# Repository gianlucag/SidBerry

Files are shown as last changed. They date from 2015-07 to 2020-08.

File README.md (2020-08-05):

## SidBerry ##
### Music player per chip SID 6581 realizzato con RaspberryPi ###

Un SID jukebox realizzato con RasberryPi e il SID chip originale 6581. Il chip è alloggiato in una board custom collegata direttamente ai GPIO del Rasberry!

(http://youtu.be/i_vNFhmKoK4)

La board può riprodurre qualsiasi SID file, basta caricare i file .sid nella sdcard del Rasberry, avviare il player e collegare all'uscita jack un paio di casse preamplificate o meglio uno stereo.

### SID chip ###

Il SID originale, nelle varianti 6581 e 8580, è controllato caricando i suoi 29 registri interni con i valori opportuni al momento opportuno. La sequenza di byte inviati genera l'effetto o la musica desiderati. Ogni registro è 1 byte ed i registri sono in tutto 29 quindi c'è bisogno di almeno 5 gpio di indirizzo (2^5=32) e 8 gpio di dati per un totale di 13 gpio. Un altro gpio è richiesto per la linea CS del chip (Chip Select).

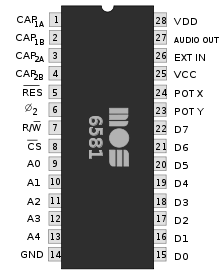
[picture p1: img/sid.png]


Fortunatamente il Raspberry ha ben 17 gpio e i 14 richiesti sono perfettamente pilotabili con la libreria WiringPi. Gli altri pin del chip servono per i due condensatori dei filtri interni (CAP_a e CAP_b), alimentazione, linea R/W (che andremo a collegare direttamente a GND, siamo sempre in scrittura), entrata del segnale di clock, linea di reset (collegata sempre a VCC) e uscita audio analogica (AUDIO OUT).

Ecco la configurazione dei registri interni del SID:

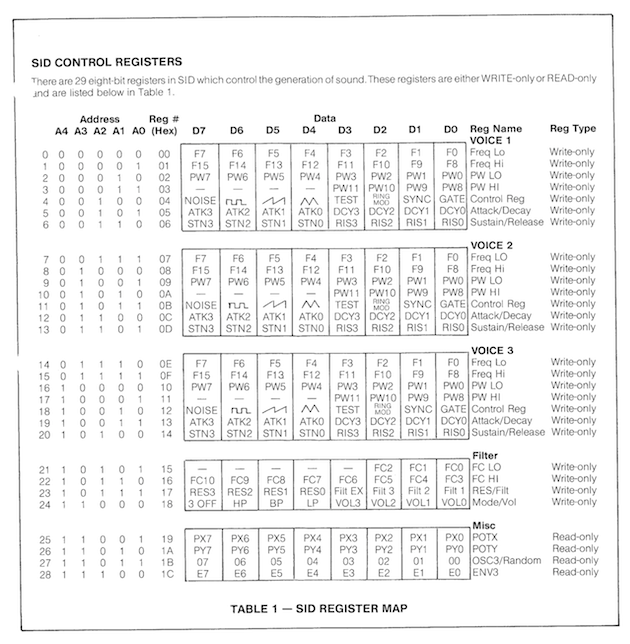
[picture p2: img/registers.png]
registers


Qui per una descrizione più dettagliata del funzionamento interno del chip:

http://www.waitingforfriday.com/index.php/Commodore_SID_6581_Datasheet

### Hardware ###

La board riproduce esattamente le "condizioni al contorno" per il SID chip come se si trovasse alloggiato in un Commodore 64 originale. L'application note originale mostra chiaramente i collegamenti da effettuare e i pochi componenti esterni richiesti (generatore di clock, condensatori e poco altro).

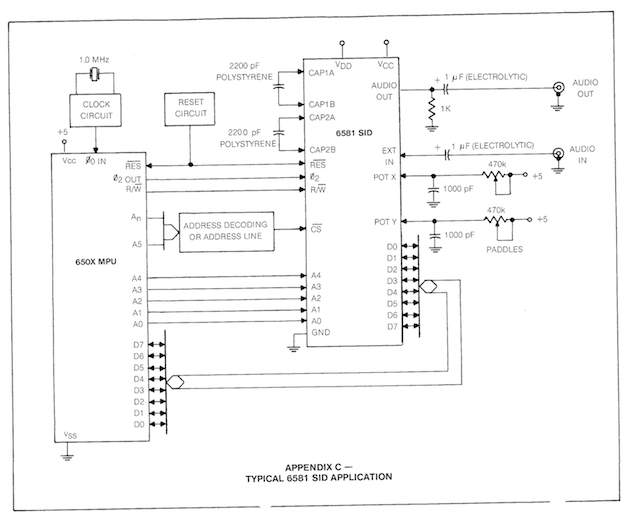
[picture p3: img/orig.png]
orig


Unica differenza, le linee di indirizzo e dati vengono dirottate direttamente sui gpio del RasberryPi.

NOTA IMPORTANTE!: Il RasberryPi ragiona in logica CMOS a 3.3V mentre il SID chip è TTL a 5V quindi completamente incompatibili a livello di tensioni. Fortunatamente, siccome andiamo unicamente a scrivere nei registri, il RasberryPi dovrà soltanto applicare 3.3v ai capi del chip, più che sufficienti per essere interpretati come livello logico alto dal SID.

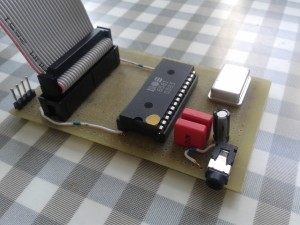
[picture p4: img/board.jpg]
board


Lo schematico completo:

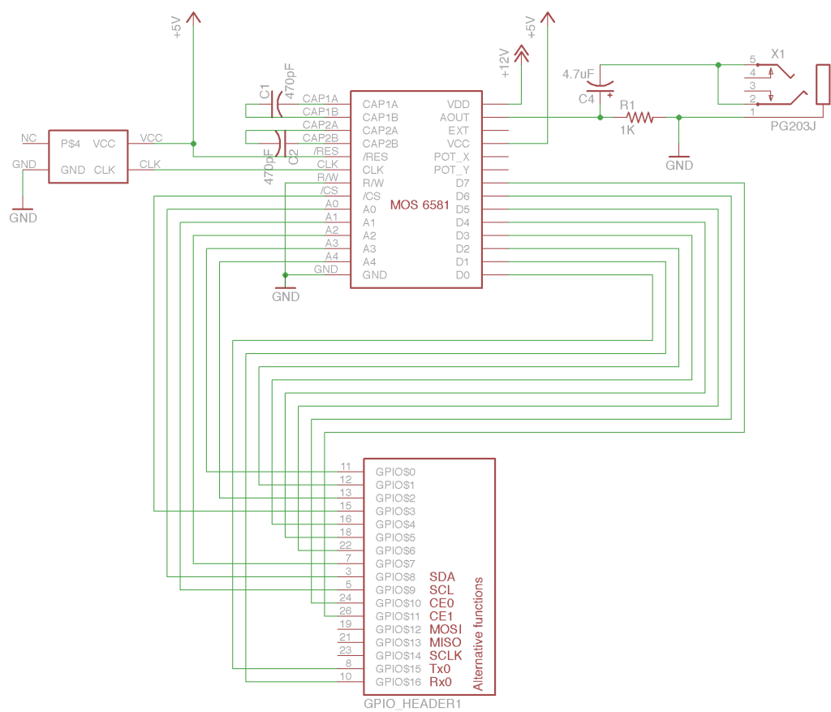
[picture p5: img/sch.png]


### Software ###

Il grosso del lavoro. Volevo una soluzione completamente stand-alone, senza l'ausilio di player esterni (come ACID64) e quindi ho realizzato un player che emula gran parte di un C64 originale. L'emulatore è necessario in quanto i file .sid sono programmi in linguaggio macchina 6502 e come tali devono essere eseguiti. Il player è scritto in C/C++ e basato sul mio emulatore MOS CPU 6502   più un semplice array di 65535 byte come memoria RAM (il C64 originale ha infatti 64K di RAM). Il player carica il codice programma contenuto nel file .sid nella RAM virtuale più un codice assembly aggiuntivo che ho chiamato micro-player: sostanzialmente si tratta di un programma minimale scritta in linguaggio macchina per CPU 6502 che assolve a due compiti specifici:

 * installare i vettori di reset e interrupt alle locazioni corrette
 * chiamare la play routine del codice sid ad ogni interrupt

Questo perchè il codice che genera la musica in un comune C64 è una funzione chiamata ad intervalli regolari (50 volte al secondo, 50Hz). La chiamata è effettuata per mezzo di un interrupt esterno. In questo modo è possibile avere musica e un qualsiasi altro programma (videogioco ad esempio) in esecuzione nello stesso momento.

Altre componenti sono il parser per i file .sid e la libreria WiringPi per pilotare i GPIO del RaspberryPi.

Questo il layout dell'intero applicativo, a destra è la memoria RAM virtuale 64K

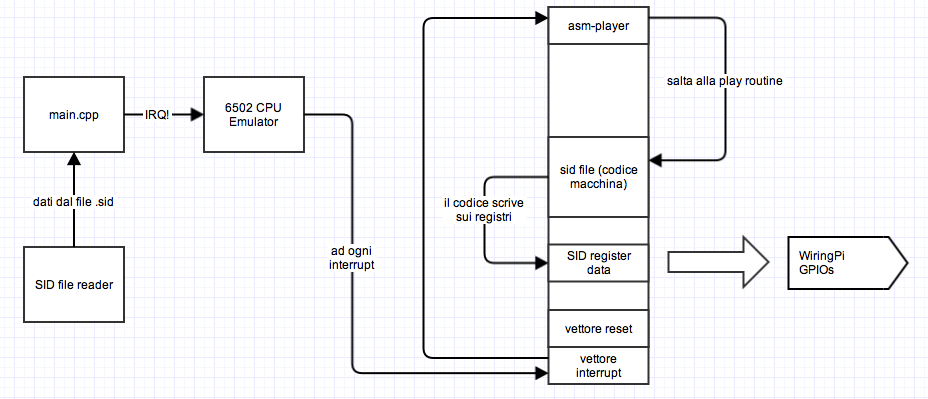
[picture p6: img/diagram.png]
layout


Questo è il codice assembler del micro-player:

```
// istallazione del vettore di reset (0x0000)
memory[0xFFFD] = 0x00;
memory[0xFFFC] = 0x00;</p>
// istallazione del vettore di interrupt, punta alla play routine (0x0013)
memory[0xFFFF] = 0x00;
memory[0xFFFE] = 0x13;

// codice del micro-player
memory[0x0000] = 0xA9;
memory[0x0001] = atoi(argv[2]); // il registro A viene caricato con il numero della traccia (0-16)

memory[0x0002] = 0x20; // salta alla init-routine nel codice sid
memory[0x0003] = init &amp; 0xFF; // lo addr
memory[0x0004] = (init &gt;&gt; 8) &amp; 0xFF; // hi addr

memory[0x0005] = 0x58; // abilitiamo gli interrupt
memory[0x0006] = 0xEA; // nop
memory[0x0007] = 0x4C; // loop infinito
memory[0x0008] = 0x06;
memory[0x0009] = 0x00;

// Interrupt service routine (ISR)
memory[0x0013] = 0xEA; // nop
memory[0x0014] = 0xEA; // nop
memory[0x0015] = 0xEA; // nop
memory[0x0016] = 0x20; // saltiamo alla play routine
memory[0x0017] = play &amp; 0xFF;
memory[0x0018] = (play &gt;&gt; 8) &amp; 0xFF;
memory[0x0019] = 0xEA; // nop
memory[0x001A] = 0x40; // return from interrupt
```
### Modifiche al Software introdotte da Alessio Lombardo ###
- Bug-Fixing (si ringrazia Thoroide, https://www.gianlucaghettini.net/sidberry2-raspberry-pi-6581-sid-player/)
- Possibilità di compilare il sorgente per diverse schede/SoC. Oltre a RaspberryPI, è direttamente supportata la scheda Acme Systems AriettaG25. Altre schede possono essere aggiunte editando opportunamente i file "gpioInterface.cpp" e "gpioInterface.h". Se necessario, è possibile fare riferimento a librerie esterne per la gestione delle porte GPIO (ad esempio, "wiringPi" nel caso di Rapsberry o "wiringSam" nel caso di Arietta).
- Aggiunti controlli al player: Pausa/Continua, traccia precedente/successiva, Restart, Uscita (con reset dei registri), Modalità Verbose.

Per la scheda AriettaG25 con libreria "wiringSAM" già installata compilare con:
```
g++ *.cpp -D BOARD='ARIETTAG25' -o sidberry -lwiringSam
```
Per la scheda RaspberryPI con libreria "wiringPi" già installata compilare con:
```
g++ *.cpp -D BOARD='RASPBERRYPI' -o sidberry -lwiringPi
```
Per altre schede, dopo aver opportunamente modificato "gpioInterface.cpp" e "gpioInterface.h", compilare con:
```
g++ *.cpp -D BOARD='CUSTOM' -o sidberry
```

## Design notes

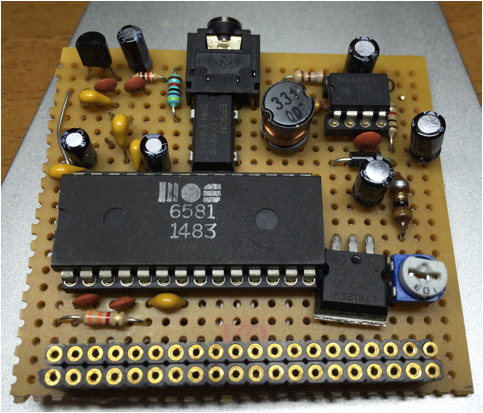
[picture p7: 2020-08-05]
hardware/Raspberry Pi/SidBerry_RaspberryPi_by_Thoroide_board2.png

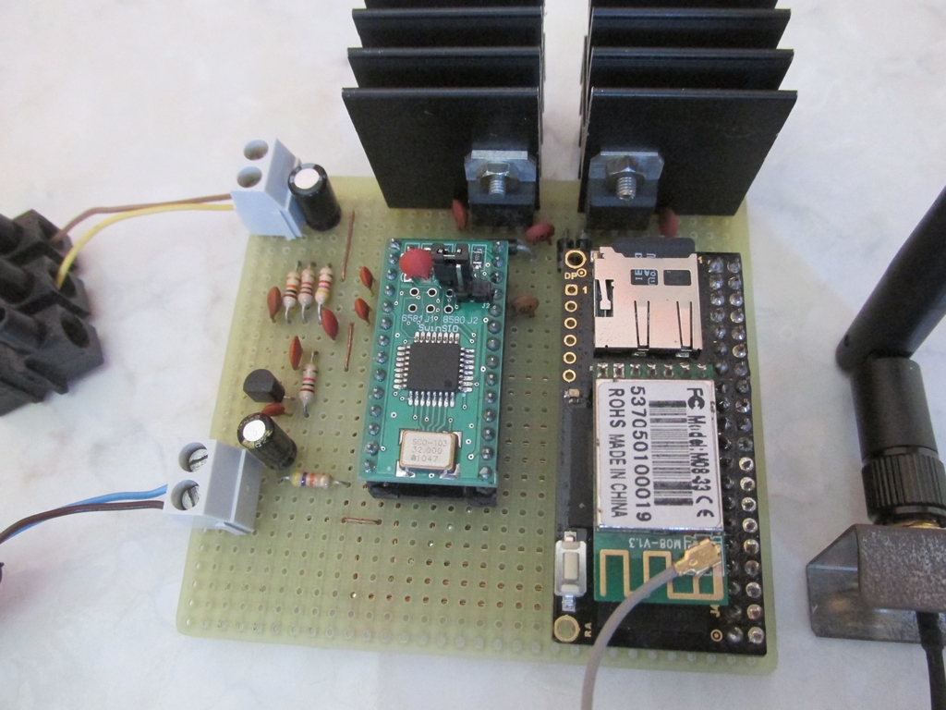
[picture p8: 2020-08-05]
hardware/Arietta G25/SidBerry_AriettaG25_board2.JPG

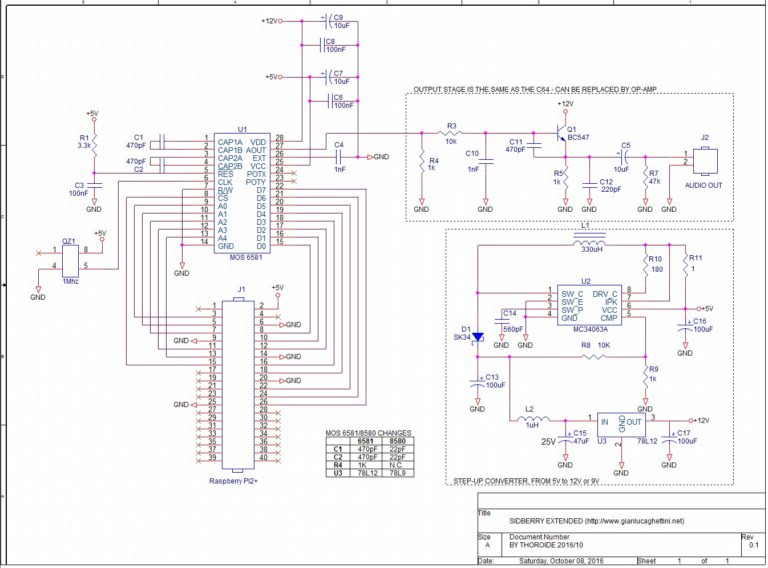
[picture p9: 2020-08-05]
hardware/Raspberry Pi/SidBerry_RaspberryPi_by_Thoroide_schematic.jpg

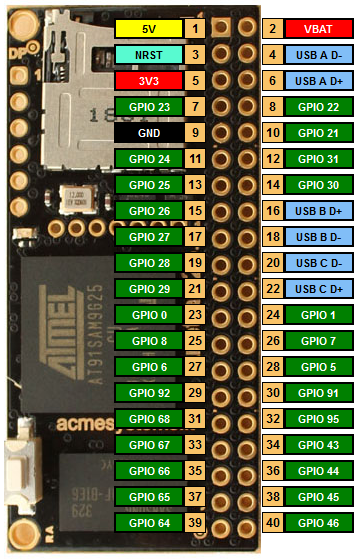
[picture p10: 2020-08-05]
hardware/Arietta G25/AriettaG25_pinout.png

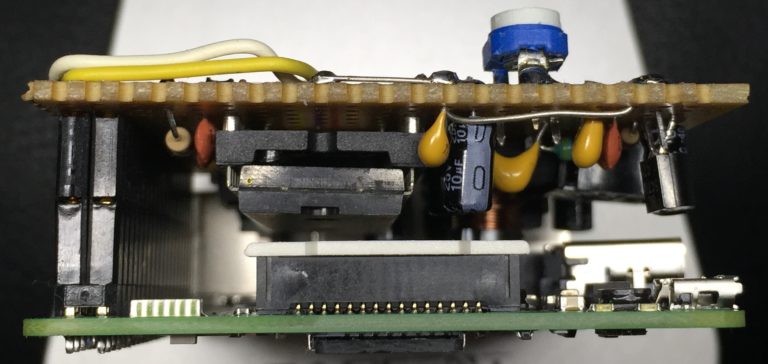
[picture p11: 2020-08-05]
hardware/Raspberry Pi/SidBerry_RaspberryPi_by_Thoroide_board3.jpg

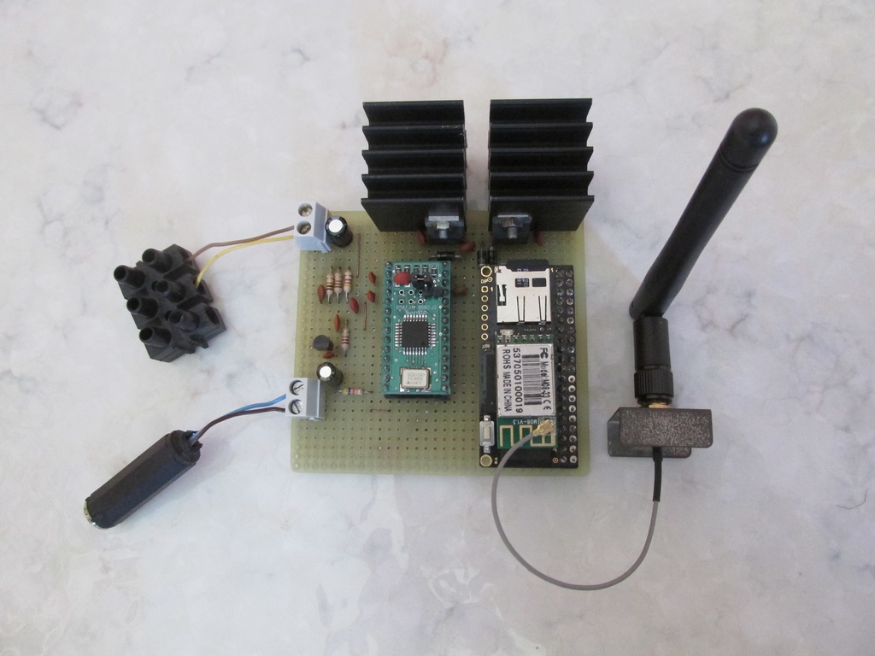
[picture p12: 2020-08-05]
hardware/Arietta G25/SidBerry_AriettaG25_board1.JPG

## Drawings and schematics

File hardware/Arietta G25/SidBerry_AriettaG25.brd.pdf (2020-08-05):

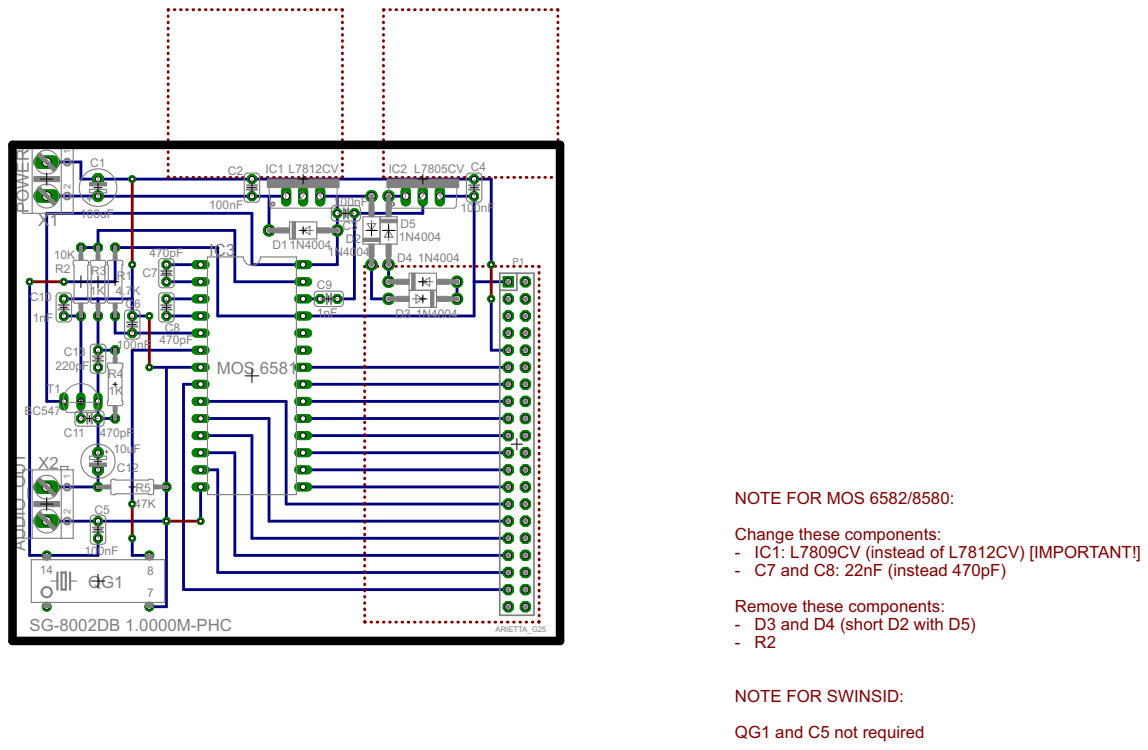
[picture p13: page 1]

NOTE FOR MOS 6582/8580: Change these components: - IC1: L7809CV (instead of L7812CV) [IMPORTANT!] - C7 and C8: 22nF (instead 470pF)

Remove these components: - D3 and D4 (short D2 with D5)

NOTE FOR SWINSID: QG1 and C5 not required

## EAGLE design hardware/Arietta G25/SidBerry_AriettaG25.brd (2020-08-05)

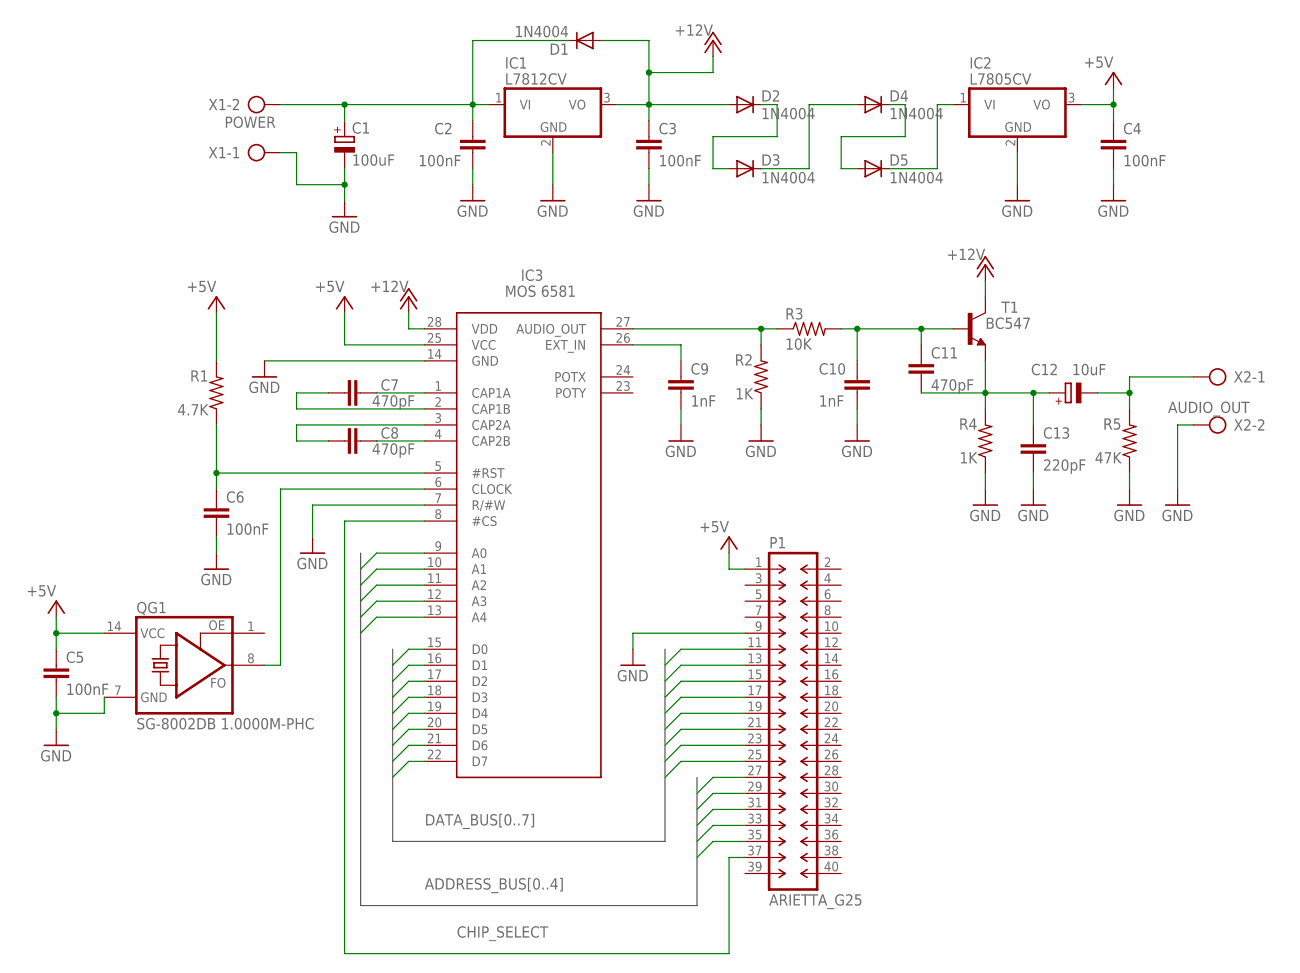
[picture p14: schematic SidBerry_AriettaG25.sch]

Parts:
C1: 100uF; E2,5-6
C2, C3, C4, C5, C6: 100nF; C025-024X044
C7, C8, C11: 470pF; C025-024X044
C9, C10: 1nF; C025-024X044
C12: 10uF; E2,5-5
C13: 220pF; C025-024X044
D1, D2, D3, D4, D5: 1N4004; DO41-10
IC1: L7812CV; TO220V
IC2: L7805CV; TO220V
IC3: MOS 6581; DIL28-6
P1: ARIETTA_G25; DIL-100-2X20
QG1: SG-8002DB 1.0000M-PHC; SG51
R1: 4.7K; 0207/10
R2, R4: 1K; 0207/10
R3: 10K; 0207/10
R5: 47K; 0207/10
T1: BC547; TO92-CBE
X1: POWER; AK500/2
X2: AUDIO_OUT; AK500/2

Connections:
+5V: C4.1, C5.1, IC2.3 (VO), IC3.25 (VCC), P1.1, QG1.14 (VCC), R1.2
+12V: C3.1, D1.A, D2.A, IC1.3 (VO), IC3.28 (VDD), T1.C
ADDRESS_BUS0: IC3.9 (A0), P1.27
ADDRESS_BUS1: IC3.10 (A1), P1.29
ADDRESS_BUS2: IC3.11 (A2), P1.31
ADDRESS_BUS3: IC3.12 (A3), P1.33
ADDRESS_BUS4: IC3.13 (A4), P1.35
CHIP_SELECT: IC3.8 (#CS), P1.37
DATA_BUS0: IC3.15 (D0), P1.25
DATA_BUS1: IC3.16 (D1), P1.23
DATA_BUS2: IC3.17 (D2), P1.21
DATA_BUS3: IC3.18 (D3), P1.19
DATA_BUS4: IC3.19 (D4), P1.17
DATA_BUS5: IC3.20 (D5), P1.15
DATA_BUS6: IC3.21 (D6), P1.13
DATA_BUS7: IC3.22 (D7), P1.11
GND: C1.-, C2.2, C3.2, C4.2, C5.2, C6.2, C9.2, C10.2, C13.2, IC1.2 (GND), IC2.2 (GND), IC3.7 (R/#W), IC3.14 (GND), P1.9, QG1.7 (GND), R2.1, R4.1, R5.1, X1.1, X2.2
unnamed: IC3.6 (CLOCK), QG1.8 (FO)
unnamed: C9.1, IC3.26 (EXT_IN)
unnamed: D2.C, D3.A
unnamed: D3.C, D4.A
unnamed: D4.C, D5.A
unnamed: D5.C, IC2.1 (VI)
unnamed: C8.2, IC3.4 (CAP2B)
unnamed: C8.1, IC3.3 (CAP2A)
unnamed: C7.1, IC3.2 (CAP1B)
unnamed: C7.2, IC3.1 (CAP1A)
unnamed: C6.1, IC3.5 (#RST), R1.1
unnamed: IC3.27 (AUDIO_OUT), R2.2, R3.1
unnamed: C1.+, C2.1, D1.C, IC1.1 (VI), X1.2
unnamed: C12.-, R5.2, X2.1
unnamed: C10.1, C11.1, R3.2, T1.B
unnamed: C11.2, C12.+, C13.1, R4.2, T1.E

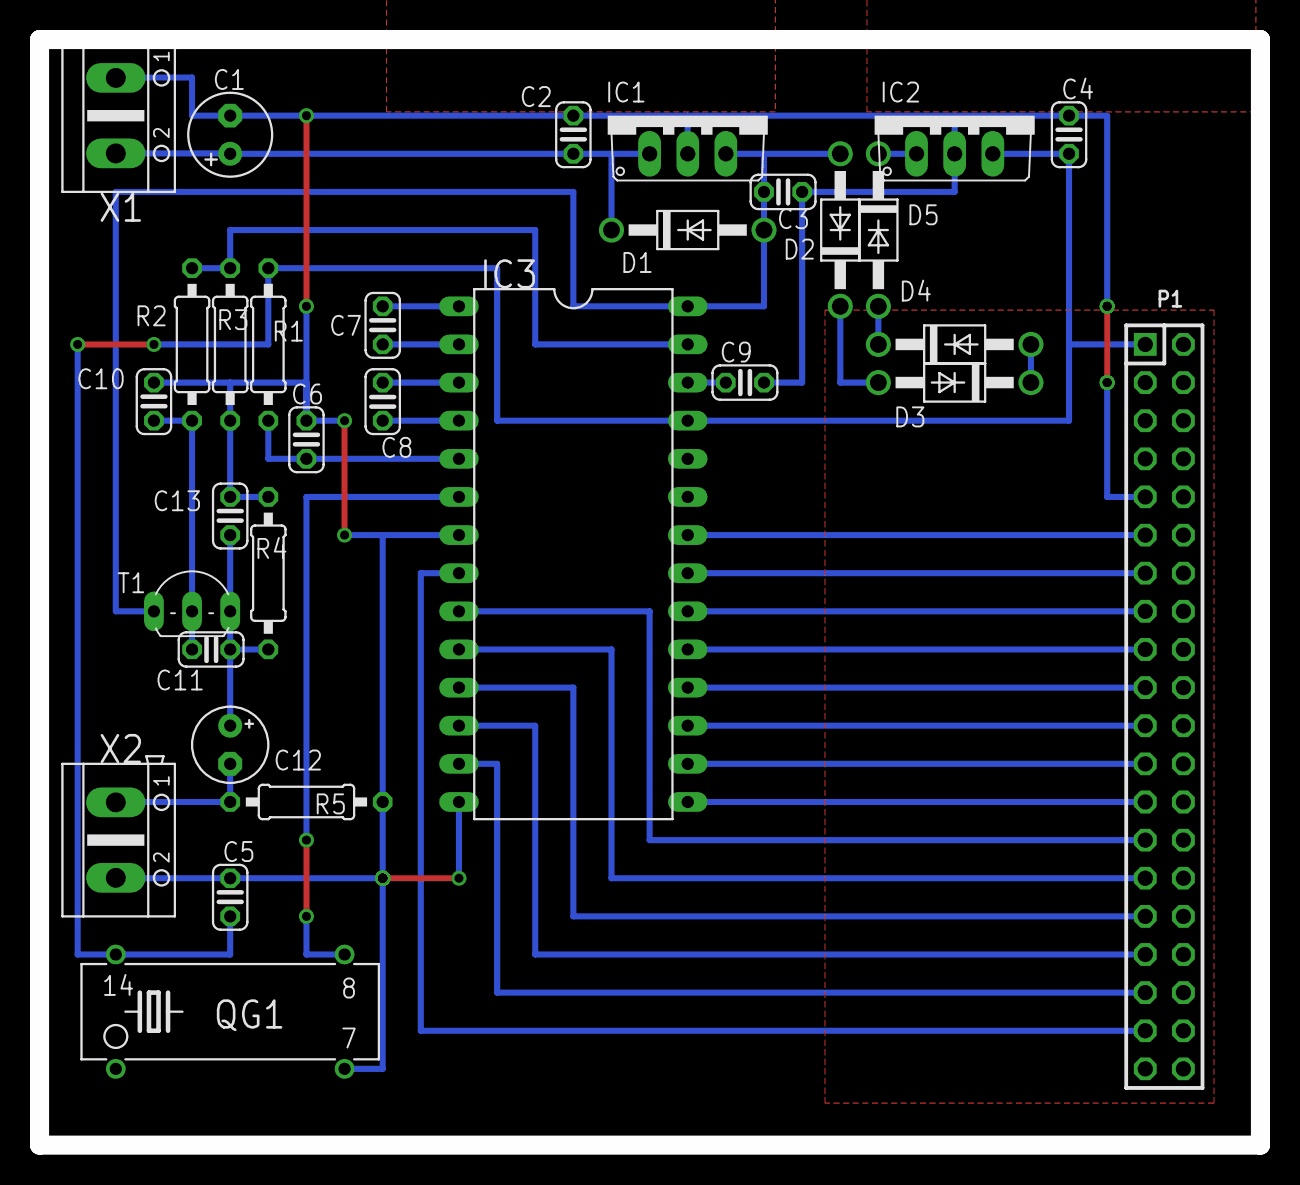
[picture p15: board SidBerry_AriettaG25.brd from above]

Board: 2 copper layers, 81.3 x 73.6 mm, 32 parts (0 on the bottom side), 33 nets.

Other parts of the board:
U$1: A4L-LOC

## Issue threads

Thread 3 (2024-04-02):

Issues on RPi4

LouDnl, 2024-04-02:
I am having issues trying to get this to run on my Pi4. I can compile it without any problems, but running it has had me banging my head. Have you seen this before?

# run with debug
```bash
└─$ sudo WIRINGPI_DEBUG=1 ./sidberry R-Type.sid

< Sid Info >
Module Name       : R-Type
Author Name       : Chris H�lsbeck & Ramiro Vaca
Copyright         :
Load Address      : 12692
Init Address      : 12692
Play Address      : 25456
Selected Sub-Song : 1 / 14
wiringPi: wiringPiSetup called
GetPiRevision: Revision string: "Revision       : c03115" (c03115) - 0xc03115
piBoardId: New Way: revision is: 00C03115
piBoardId: rev: 5, type: 17, proc: 3, mfg: 0, mem: 4, warranty: 0
wiringPi: access to /dev/mem succeded
wiringPi: memory map gpio  0xfe200000 valid
wiringPi: memory map pads  0xfe100000 valid
wiringPi: memory map rio   0x0 invalid
wiringPi: memory map pwm   0xfe20c000 valid
wiringPi: memory map clk   0xfe101000 valid
wiringPi: memory map timer 0xfe00b000 valid
pinMode: pin:27 mode:1
pinMode: bcm pin:16 mode:1
pinMode: pin:28 mode:1
pinMode: bcm pin:20 mode:1
pinMode: pin:29 mode:1
pinMode: bcm pin:21 mode:1
pinMode: pin:4 mode:1
pinMode: bcm pin:23 mode:1
pinMode: pin:5 mode:1
pinMode: bcm pin:24 mode:1
pinMode: pin:6 mode:1
pinMode: bcm pin:25 mode:1
pinMode: pin:10 mode:1
pinMode: bcm pin:8 mode:1
pinMode: pin:11 mode:1
pinMode: bcm pin:7 mode:1
pinMode: pin:8 mode:1
pinMode: bcm pin:2 mode:1
pinMode: pin:9 mode:1
pinMode: bcm pin:3 mode:1
pinMode: pin:7 mode:1
pinMode: bcm pin:4 mode:1
pinMode: pin:0 mode:1
pinMode: bcm pin:17 mode:1
pinMode: pin:2 mode:1
pinMode: bcm pin:27 mode:1
pinMode: pin:3 mode:1
pinMode: bcm pin:22 mode:1
zsh: illegal hardware instruction  sudo WIRINGPI_DEBUG=1 ./sidberry R-Type.sid
```

# gdb
```bash
└─$ sudo gdb --args sidberry R-Type.sid
GNU gdb (Debian 13.2-1) 13.2
Copyright (C) 2023 Free Software Foundation, Inc.
License GPLv3+: GNU GPL version 3 or later <http://gnu.org/licenses/gpl.html>
This is free software: you are free to change and redistribute it.
There is NO WARRANTY, to the extent permitted by law.
Type "show copying" and "show warranty" for details.
This GDB was configured as "arm-linux-gnueabihf".
Type "show configuration" for configuration details.
For bug reporting instructions, please see:
<https://www.gnu.org/software/gdb/bugs/>.
Find the GDB manual and other documentation resources online at:
    <http://www.gnu.org/software/gdb/documentation/>.

For help, type "help".
Type "apropos word" to search for commands related to "word"...
Reading symbols from sidberry...
(gdb) r
Starting program: /home/loud/development/SidBerry/sidberry R-Type.sid
[Thread debugging using libthread_db enabled]
Using host libthread_db library "/lib/arm-linux-gnueabihf/libthread_db.so.1".

< Sid Info >
Module Name       : R-Type
Author Name       : Chris H�lsbeck & Ramiro Vaca
Copyright         :
Load Address      : 12692
Init Address      : 12692
Play Address      : 25456
Selected Sub-Song : 1 / 14

Program received signal SIGILL, Illegal instruction.
0x00401da4 in load_sid (cpu=..., sid=<error reading variable: value of type `SidFile' requires 65640 bytes, which is more than max-value-size>, song_number=0) at main.cpp:278
278             cpu.Run(10000000);
```

LouDnl, 2024-04-03:
Got it working, the issue was with `load_sid` being int without a return. Changing it to `void load_sid` fixed all issues.

gianlucag, 2024-04-04:
Good catch. Please feel free to submit a pull request if you want.

LouDnl, 2024-04-08:
Since i've got it working I can notice that the timing sometimes seems off and tunes don't always play all notes. Have you seen/ heard this before?

LouDnl, 2024-05-12:
@gianlucag decided to create a fork because I made so many changes it wouldnt be fair for me to decide what you want and dont want 🙂

https://github.com/LouDnl/SidBerry

Closed 2024-05-07.

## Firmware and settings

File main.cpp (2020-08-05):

//============================================================================
// Description : SidBerry player & driver 
// Author      : Gianluca Ghettini, Alessio Lombardo
//============================================================================

#include <iostream>
using namespace std;
#include <stdlib.h>
#include "mos6502.h"
#include "SidFile.h"
#include <sys/time.h>
#include <unistd.h>
#include <fcntl.h>
#include <termios.h>

#include "gpioInterface.h"

uint8_t memory[65536]; // 64K ram
bool verbose = false;

void TestWrite(uint16_t addr, uint8_t byte)
{	
		printf("\na: %02X, b: %02X", addr, byte);		
		
		uint16_t phyaddr = addr;
		
		// set address to the bus
		if(phyaddr & 0x01) gpioWrite(A0, HIGH);
		else gpioWrite(A0, LOW);
		if(phyaddr & 0x02) gpioWrite(A1, HIGH);
		else gpioWrite(A1, LOW);
		if(phyaddr & 0x04) gpioWrite(A2, HIGH);
		else gpioWrite(A2, LOW);
		if(phyaddr & 0x08) gpioWrite(A3, HIGH);
		else gpioWrite(A3, LOW);
		if(phyaddr & 0x10) gpioWrite(A4, HIGH);
		else gpioWrite(A4, LOW);
		
		// set data to the bus
		if(byte & 0x01) gpioWrite(D0, HIGH);
		else gpioWrite(D0, LOW);
		if(byte & 0x02) gpioWrite(D1, HIGH);
		else gpioWrite(D1, LOW);
		if(byte & 0x04) gpioWrite(D2, HIGH);
		else gpioWrite(D2, LOW);
		if(byte & 0x08) gpioWrite(D3, HIGH);
		else gpioWrite(D3, LOW);
		if(byte & 0x10) gpioWrite(D4, HIGH);
		else gpioWrite(D4, LOW);			
		if(byte & 0x20) gpioWrite(D5, HIGH);
		else gpioWrite(D5, LOW);
		if(byte & 0x40) gpioWrite(D6, HIGH);
		else gpioWrite(D6, LOW);
		if(byte & 0x80) gpioWrite(D7, HIGH);
		else gpioWrite(D7, LOW);		
		
		// assert cs line
		gpioWrite(CS, LOW);
		usleep(500000);		
		gpioWrite(CS, HIGH);	

	printf("\nOK\n");

	return;
}

void MemWrite(uint16_t addr, uint8_t byte)
{	
	if(addr >= 0xD400 && addr <= 0xD7FF) // address decoding login
	{
		// access to SID chip
		
		memory[addr] = byte;

		if(verbose){
			//NOTE: If you use a slow connection to tty device, the printf function may affect the playback speed
			printf("%02X%02X %02X%02X %02X %02X %02X %02X%02X %02X%02X %02X %02X %02X %02X%02X %02X%02X %02X %02X %02X\n",
					memory[0xD400], memory[0xD401], memory[0xD402], memory[0xD403],memory[0xD404], memory[0xD405], memory[0xD406],
					memory[0xD407], memory[0xD408], memory[0xD409], memory[0xD40A],memory[0xD40B], memory[0xD40C], memory[0xD40D],
					memory[0xD40E], memory[0xD40F], memory[0xD410], memory[0xD411],memory[0xD412], memory[0xD413], memory[0xD414]
			);
		}
		
		uint16_t phyaddr = addr & 0x1f;
		
		// set address to the bus
		if(phyaddr & 0x01) gpioWrite(A0, HIGH);
		else gpioWrite(A0, LOW);
		if(phyaddr & 0x02) gpioWrite(A1, HIGH);
		else gpioWrite(A1, LOW);
		if(phyaddr & 0x04) gpioWrite(A2, HIGH);
		else gpioWrite(A2, LOW);
		if(phyaddr & 0x08) gpioWrite(A3, HIGH);
		else gpioWrite(A3, LOW);
		if(phyaddr & 0x10) gpioWrite(A4, HIGH);
		else gpioWrite(A4, LOW);
		
		// set data to the bus
		if(byte & 0x01) gpioWrite(D0, HIGH);
		else gpioWrite(D0, LOW);
		if(byte & 0x02) gpioWrite(D1, HIGH);
		else gpioWrite(D1, LOW);
		if(byte & 0x04) gpioWrite(D2, HIGH);
		else gpioWrite(D2, LOW);
		if(byte & 0x08) gpioWrite(D3, HIGH);
		else gpioWrite(D3, LOW);
		if(byte & 0x10) gpioWrite(D4, HIGH);
		else gpioWrite(D4, LOW);			
		if(byte & 0x20) gpioWrite(D5, HIGH);
		else gpioWrite(D5, LOW);
		if(byte & 0x40) gpioWrite(D6, HIGH);
		else gpioWrite(D6, LOW);
		if(byte & 0x80) gpioWrite(D7, HIGH);
		else gpioWrite(D7, LOW);		
		
		// assert CS line (strobe)
		gpioWrite(CS, LOW);
		usleep(1);		
		gpioWrite(CS, HIGH);	
	}
	else
	{
		// access to memory
		memory[addr] = byte;
	}
	return;
}

uint8_t MemRead(uint16_t addr)
{
	if(addr >= 0xD400 && addr <=0xD7FF) // address decoding logic
	{
		// access to SID chip
		if((addr & 0x00FF) == 0x001B)
		{
			// emulate read access to OSC3/Random register, return a random value
			printf("\nread! 1b");
			return rand();
		}
		if((addr & 0x00FF) == 0x001C)
		{
			// emulate access to envelope ENV3 register, return a random value
			printf("\nread! 1c");
			return rand();
		}
    }
	return memory[addr];
}

void TestLoop()
{
	int addr;
	int byte;
	printf("\n\n");

	while(1)
	{
		printf("\naddr:");
		scanf("%d", &addr);
		printf("\nbyte:");
		scanf("%d", &byte);
		TestWrite(addr, byte); 
	}	

}

int load_sid(mos6502 cpu, SidFile sid, int song_number){
	for(unsigned int i = 0; i < 65536; i++)
	{
		memory[i] = 0x00; // fill with NOPs
	}
	
	uint16_t load = sid.GetLoadAddress();
	uint16_t len = sid.GetDataLength();
	uint8_t *buffer = sid.GetDataPtr();
	for(unsigned int i = 0; i <  len; i++)
	{
		memory[i + load] = buffer[i];
	}
	
	uint16_t play = sid.GetPlayAddress();
	uint16_t init = sid.GetInitAddress();
	
	
	// install reset vector for microplayer (0x0000)
	memory[0xFFFD] = 0x00;
	memory[0xFFFC] = 0x00;
	
	// install IRQ vector for play routine launcher (0x0013)
	memory[0xFFFF] = 0x00;
	memory[0xFFFE] = 0x13;
	

	// install the micro player, 6502 assembly code
	 
	memory[0x0000] = 0xA9; // A = 0, load A with the song number
	memory[0x0001] = song_number;
	
	memory[0x0002] = 0x20; // jump sub to INIT routine
	memory[0x0003] = init & 0xFF; // lo addr
	memory[0x0004] = (init >> 8) & 0xFF; // hi addr
	
	memory[0x0005] = 0x58; // enable interrupt
	memory[0x0006] = 0xEA; // nop
	memory[0x0007] = 0x4C; // jump to 0x0006
	memory[0x0008] = 0x06;
	memory[0x0009] = 0x00;
	
	memory[0x0013] = 0xEA; // nop  //0xA9; // A = 1
	memory[0x0014] = 0xEA; // nop //0x01;	
	memory[0x0015] = 0xEA; // 0x78 CLI
	memory[0x0016] = 0x20; // jump sub to play routine
	memory[0x0017] = play & 0xFF;
	memory[0x0018] = (play >> 8) & 0xFF;
	memory[0x0019] = 0xEA; // 0x58 SEI	
	memory[0x001A] = 0x40; // RTI: return from interrupt
	
	// setup wiring library, configure GPIOs
	gpioSetup();
	
	gpioMode(D0, OUTPUT);
	gpioMode(D1, OUTPUT);
	gpioMode(D2, OUTPUT);
	gpioMode(D3, OUTPUT);
	gpioMode(D4, OUTPUT);
	gpioMode(D5, OUTPUT);
	gpioMode(D6, OUTPUT);
	gpioMode(D7, OUTPUT);
	
	gpioMode(A0, OUTPUT);
	gpioMode(A1, OUTPUT);
	gpioMode(A2, OUTPUT);
	gpioMode(A3, OUTPUT);
	gpioMode(A4, OUTPUT);
	
	gpioMode(CS, OUTPUT);
	
	gpioWrite(D0, LOW);
	gpioWrite(D1, LOW);
	gpioWrite(D2, LOW);
	gpioWrite(D3, LOW);
	gpioWrite(D4, LOW);
	gpioWrite(D5, LOW);
	gpioWrite(D6, LOW);
	gpioWrite(D7, LOW);
	
	gpioWrite(A0, LOW);
	gpioWrite(A1, LOW);	
	gpioWrite(A2, LOW);
	gpioWrite(A3, LOW);
	gpioWrite(A4, LOW);

	gpioWrite(CS, HIGH);
	
	cpu.Reset();
	//cpu.Run(10000000);
	cpu.Run(100000);

}

int getch_noecho_special_char() {
	
	int char_code = 0;
	int buf = 0;
	char buf2[3] = {0,0,0};
	const char* buf_erase_echo = string("\033[2K\r").data();
	
    struct termios old = {0};
    tcgetattr(0, &old);
    old.c_lflag &= ~ICANON;
    old.c_lflag &= ~ECHO;
    old.c_cc[VMIN] = 0;
    old.c_cc[VTIME] = 0;
    tcsetattr(0, TCSANOW, &old);
	
	read(0, &buf2[0], 1);
	read(0, &buf2[1], 1);
	read(0, &buf2[2], 1);
	if(buf2[0]!=0) write(0, buf_erase_echo, 5);

	if(buf2[0]=='\033' && buf2[1]=='\0'){ //Escape Key
		buf=256;
	}else if(buf2[0]=='\033' && buf2[1]==91 && buf2[2]==68 ){ //Left Arrow
		buf=257;
	}else if(buf2[0]=='\033' && buf2[1]==91 && buf2[2]==67 ){ //Right Arrow
		buf=258;
	}else{
		buf=buf2[0];
	}
				
    old.c_lflag |= ICANON;
    old.c_lflag |= ECHO;
    tcsetattr(0, TCSADRAIN, &old);
	
    return buf;
	
}

void change_player_status(mos6502 cpu, SidFile sid, int key_press, bool* paused, bool* exit, uint8_t* mode_vol_reg, int* song_number, int* sec, int* min){
	if(key_press==256 || key_press==(int)'q'){ //Escape (reset all registers and quit)
		printf("Exit\n");
		for(int i=0xD400;i<0xD414;i++){
			MemWrite(i, 0);
		}
		*paused=false;
		*exit=true;
	}else if(key_press==32){ //Pause
		if(*paused){
			printf("\rPlay Sub-Song %d / %d [%02d:%02d]",(*song_number)+1,sid.GetNumOfSongs(),*min,*sec); fflush(stdout);
			MemWrite(0xD418, *mode_vol_reg);		
			*paused=false;		
		}else{
			printf("\rPlay Sub-Song %d / %d [%02d:%02d][PAUSE]",(*song_number)+1,sid.GetNumOfSongs(),*min,*sec); fflush(stdout);	
			*mode_vol_reg = MemRead(0xD418);		
			MemWrite(0xD418, 0);		
			*paused=true;	
		}
	}else if(key_press==(int)'v'){
		verbose = !verbose;
		if(verbose) cout << "VERBOSE" << endl;
		else cout << "NO VERBOSE" << endl;
	}else if(key_press==(int)'r'){
		load_sid(cpu,sid,*song_number);
		*min=0;
		*sec=0;
		*paused=false;
		printf("\rPlay Sub-Song %d / %d [%02d:%02d]",(*song_number)+1,sid.GetNumOfSongs(),*min,*sec); fflush(stdout);
	}else if(key_press==257){ //Previous Sub-Song
		(*song_number)--;
		if(*song_number<0) *song_number=sid.GetNumOfSongs()-1;
		load_sid(cpu,sid,*song_number);	
		*min=0;
		*sec=0;
		*paused=false;
		printf("\rPlay Sub-Song %d / %d [%02d:%02d]",(*song_number)+1,sid.GetNumOfSongs(),*min,*sec); fflush(stdout);
	}else if(key_press==258){ //Next Sub-Song
		(*song_number)++;
		if(*song_number==sid.GetNumOfSongs()) (*song_number)=0;
		load_sid(cpu,sid,*song_number);
		*min=0;
		*sec=0;
		*paused=false;		
		printf("\rPlay Sub-Song %d / %d [%02d:%02d]",(*song_number)+1,sid.GetNumOfSongs(),*min,*sec); fflush(stdout);
	}else if(key_press>0){
		if(*paused){
			printf("\rPlay Sub-Song %d / %d [%02d:%02d][PAUSE]",(*song_number)+1,sid.GetNumOfSongs(),*min,*sec); fflush(stdout);
		}else{
			printf("\rPlay Sub-Song %d / %d [%02d:%02d]",(*song_number)+1,sid.GetNumOfSongs(),*min,*sec); fflush(stdout);		
		}
	}
	
}



int main(int argc, char *argv[])
{
	SidFile sid;
	
	string filename = "";
    int song_number = 0;
	
	for(int param_count = 1;param_count<argc;param_count++){
		if(filename.length()==0 and argv[param_count][0]!='-'){
			filename=argv[param_count];			
		}else if(!strcmp(argv[param_count],"-v") || !strcmp(argv[param_count],"--verbose")){
			verbose = true;
		}else if(!strcmp(argv[param_count],"-V") || !strcmp(argv[param_count],"--version")){
			cout << "SidBerry 3.0 - (July 2020)" << endl;
			cout << "MOS SID (MOS6581/8580) Player for RaspberryPI, AriettaG25 and others Linux-based systems with GPIO ports" <<endl;
			cout << "Hardware for RaspberryPI : Gianluca Ghettini, Thoroide "<< endl;
			cout << "Hardware for AriettaG25  : Alessio Lombardo " << endl;
			cout << "Low-level interface      : Gianluca Ghettini, Alessio Lombardo " << endl;
			cout << "MOS6502 Emulator         : Gianluca Ghettini" << endl;
			cout << "Sid Player               : Gianluca Ghettini, Alessio Lombardo " << endl;
		}else if(!strcmp(argv[param_count],"-s") || !strcmp(argv[param_count],"--song")){
			param_count++;
			song_number = atoi(argv[param_count])-1;
		}else if(!strcmp(argv[param_count],"-h") || !strcmp(argv[param_count],"--help")){
			cout << "Usage: " << argv[0] << " <Sid Filename> [Options]" << endl;
			cout << "Options: " << endl;
			cout << " -s, --song    : Set Sub-Song number (default depends on the Sid File) " << endl;			
			cout << " -v, --verbose : Verbose mode (show SID registers content) " << endl;
			cout << " -V, --version : Show version and other informations " << endl;
			cout << " -h, --help    : Show this help message " << endl;
			return 0;
		}else{
			cout << "Warning: Invalid Parameter at position " << param_count << endl;
		}
		
	}
	
	int res = sid.Parse(filename);
	if(song_number<0 or song_number>=sid.GetNumOfSongs()){
		cout << "Warning: Invalid Sub-Song Number. Default Sub-Song will be chosen." << endl;
		song_number=sid.GetFirstSong();	
	}
	
	if(res == SIDFILE_ERROR_FILENOTFOUND)
	{
		cerr << "error loading sid file! not found" << endl;
		return 1;
	}
	
	if(res == SIDFILE_ERROR_MALFORMED)
	{
		cerr << "error loading sid file! malformed" << endl;
		return 2;
	}
	cout << "\n< Sid Info >" << endl;	
	cout << "Module Name       : " << sid.GetModuleName() << endl ;
	cout << "Author Name       : " << sid.GetAuthorName() << endl ;
	cout << "Copyright         : " << sid.GetCopyrightInfo() << endl ;
	
	cout << "Load Address      : " << sid.GetLoadAddress() << endl ;
	cout << "Init Address      : " << sid.GetInitAddress() << endl ;
	cout << "Play Address      : " << sid.GetPlayAddress() << endl ;

	cout << "Selected Sub-Song : " << song_number+1 << " / " << sid.GetNumOfSongs() << endl ;

    srand(0);
	mos6502 cpu(MemRead, MemWrite);
	
	int time_unit = 0;
	int sec = 0;
	int min = 0;

	timeval t1,t2;
	long int elaps;

	load_sid(cpu,sid,song_number);
	
	if(verbose) cout << endl;
	
	cout << "\n< Player Commands >" << endl;
	cout << "Space       : Pause/Continue " << endl;
	cout << "Left  Arrow : Previous Sub-Song " << endl;
	cout << "Right Arrow : Next Sub-Song " << endl;	
	cout << "R           : Restart current Sub-Song " << endl;	
	cout << "V           : Verbose (show SID registers) " << endl;	
	cout << "Q or Escape : Quit " << endl << endl;
	
	printf("\rPlay Sub-Song %d / %d [%02d:%02d]",song_number+1,sid.GetNumOfSongs(),min,sec); fflush(stdout);
	
	bool paused = false;
	bool exit = false;
	uint8_t mode_vol_reg = 0;

	
	// main loop, play song
	while(!exit)
	{
		
		while(paused){	
			change_player_status(cpu, sid, getch_noecho_special_char(),&paused,&exit,&mode_vol_reg,&song_number, &sec, &min);
			usleep(100000);
		}
		
		gettimeofday(&t1, NULL);	

		change_player_status(cpu, sid, getch_noecho_special_char(),&paused,&exit,&mode_vol_reg,&song_number, &sec, &min);
		
		if(exit) break;
		if(paused) continue;

		
		// trigger IRQ interrupt
		cpu.IRQ();
		
		// execute the player routine
		cpu.Run(0);
		
		gettimeofday(&t2, NULL);

		// wait 1/50 sec. 
		if(t1.tv_sec == t2.tv_sec) elaps = t2.tv_usec - t1.tv_usec;
		else elaps = 1000000 - t1.tv_usec + t2.tv_usec;
		if(elaps < 20000) usleep(20000 - elaps); // 50Hz refresh rate
		time_unit++;		
		if(time_unit%50==0){
			sec++;
			if(sec==60){
				sec=0;
				min++;
			}
			if(!verbose){
				printf("\rPlay Sub-Song %d / %d [%02d:%02d]",song_number+1,sid.GetNumOfSongs(),min,sec); fflush(stdout);
			}
		}
	}
	
	return 0;
}

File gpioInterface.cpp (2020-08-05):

//============================================================================
// Description : SidBerry wrapper to GPIO ports
// Author      : Alessio Lombardo
//============================================================================

#include "gpioInterface.h"

#if BOARD == RASPBERRYPI				//Raspberry Pi (GPIO library: <wiringPi.h>)

void gpioWrite(int pin, int level){
	digitalWrite(pin, level);
}

int gpioSetup(){
	wiringPiSetup();
}

void gpioMode(int pin, int mode){
	pinMode(pin, mode);
}
	
#elif BOARD == ARIETTAG25				//Acme Systems Arietta G25 (GPIO library: <wiringSam.h>)

void gpioWrite(int pin, int level){
	if (pin>=0 && pin<32) digitalWrite(WSAM_PIO_A, pin, level);
	else if (pin>=32 && pin<64) digitalWrite(WSAM_PIO_B, pin-32, level);
	else if (pin>=64 && pin<96) digitalWrite(WSAM_PIO_C, pin-64, level);
}

int gpioSetup(){
	wiringSamSetup();
}

void gpioMode(int pin, int mode){
	FILE *fp=fopen("/sys/class/gpio/export","w");
	fprintf(fp,"%d",pin);
	fclose(fp);
	if (pin>=0 && pin<32) pinMode(WSAM_PIO_A, pin, mode);
	else if (pin>=32 && pin<64) pinMode(WSAM_PIO_B, pin-32, mode);
	else if (pin>=64 && pin<96) pinMode(WSAM_PIO_C, pin-64, mode);
}

#elif BOARD == CUSTOM					//Custom Board

/*
 *	Function to WRITE to a GPIO port. Map this function to the equivalent GPIO library function or write it.
 */
void gpioWrite(int pin, int level){
	
}

/*
 *	Function to SETUP the GPIO ports. Map this function to the equivalent GPIO library function or write it.
 */
int gpioSetup(){
}

/*
 *	Function to set the MODE of a GPIO port. Map this function to the equivalent GPIO library function or write it.
 */
void gpioMode(int pin, int mode){
}
	
#endif

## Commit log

2015-07-04 Sidberry SID player for raspberryPi
2020-07-12 Interface to support different systems (RaspberryPi, AriettaG25, Custom Board).
2020-08-05 Add schematics and boards
    [SidBerry_AriettaG25.brd, SidBerry_AriettaG25.sch]

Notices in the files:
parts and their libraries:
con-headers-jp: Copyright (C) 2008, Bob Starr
